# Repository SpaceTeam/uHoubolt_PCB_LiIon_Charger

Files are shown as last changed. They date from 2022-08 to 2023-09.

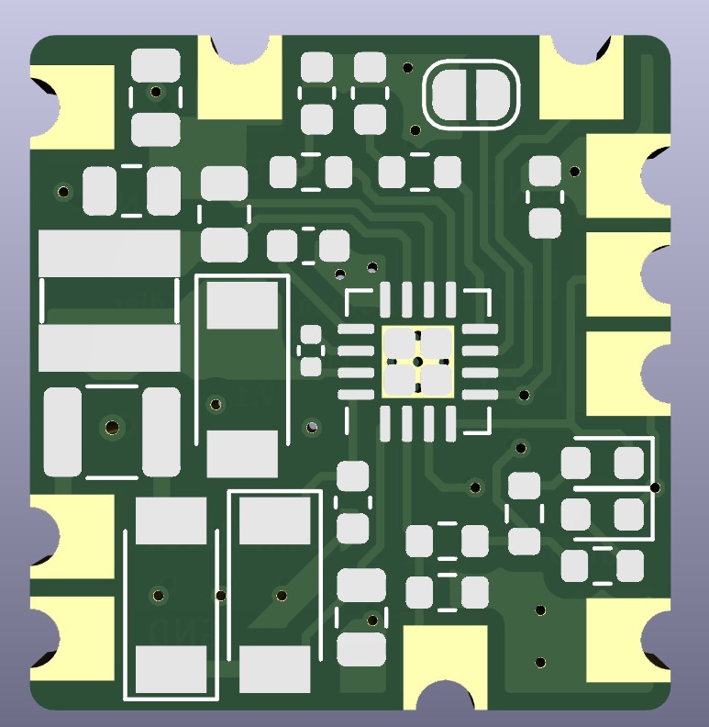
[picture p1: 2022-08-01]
LiIon_Charger_Front.jpg

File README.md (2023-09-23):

# uHoubolt LiIon Charger

Small sized PCB (19mm x 20mm). Used to control and monitor the charging process of a connected LiIon Battery. Soldered to the PMU via edge connectors. Most of the connectors serve a controling function to check the different circuits of the board.

## Features
- Edge connectors
- LED charging state indicator
- Footprint for the connecting PCB
- Known Issues
- The PCB is very noisy
- Did not properly work during EuRoC

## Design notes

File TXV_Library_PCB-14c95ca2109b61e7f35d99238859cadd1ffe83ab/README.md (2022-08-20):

# µHoubolt/Houbolt/TXV KiCad Library

## Usage
Add this repository to the KiCad project directory as a submodule

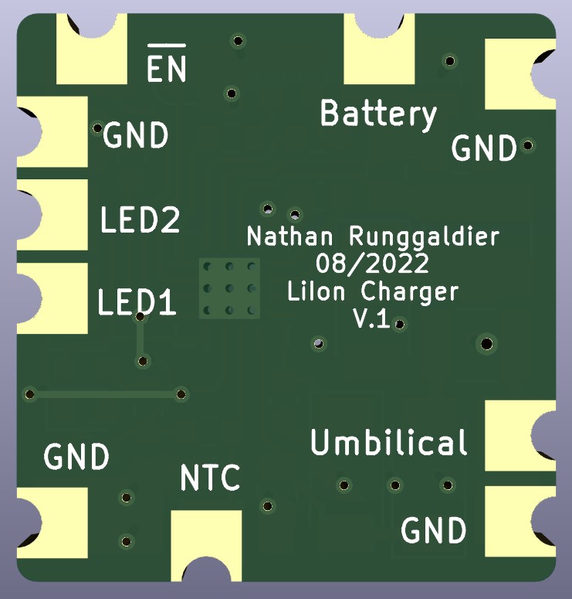
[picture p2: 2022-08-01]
LiIon_Charger_Back.jpg

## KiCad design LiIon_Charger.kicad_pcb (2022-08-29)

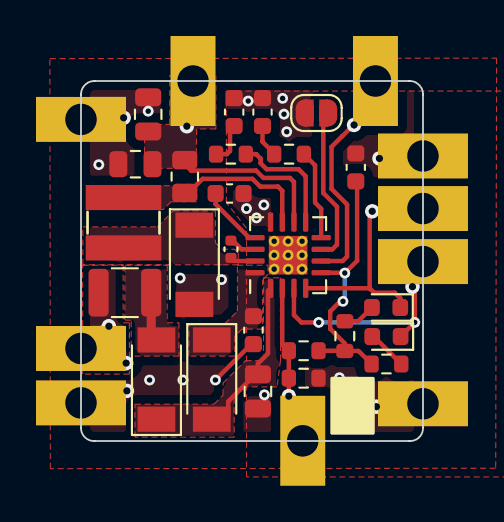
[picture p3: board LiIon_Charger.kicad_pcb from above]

Board: 2 copper layers, 19.0 x 20.0 mm, 35 parts (0 on the bottom side), 22 nets.

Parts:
C1, C8, C9: 22u; C_0805_2012Metric
C2, C3: 22u; C_0603_1608Metric
C4: 100n; C_0603_1608Metric
C5: 100n; C_0402_1005Metric
C6, C7: 2.2n; C_0603_1608Metric
D1, D4, D5: PMEG3050EP; D_SOD-128
D2, D3: LED; LED_0603_1608Metric
F1: Fuse_Small; R_1210_3225Metric
H1, H2, H3, H4: MountingHole_Pad; Edge_Connector
JP1: SolderJumper_2_Open; SolderJumper-2_P1.3mm_Open_RoundedPad1.0x1.5mm
L1: 4.7u; SRN4018TA-4R7M
R1, R2: 10k; R_0603_1608Metric
R3, R4: 120; R_0603_1608Metric
R5: 750; R_0603_1608Metric
R6: 2.61k; R_0603_1608Metric
R7: 200m; R_0805_2012Metric
U1: MP26123; QFN-16-1EP_4x4mm_P0.65mm_EP2.15x2.15mm_ThermalVias
j1, j2, j3, j4, j5, j6: Conn_01x01; Edge_Connector

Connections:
/Battery: C8.1, C9.1, R7.1, U1.10 (BATT), j6.1
/Charger: F1.1, j1.1
/NTC: R1.2, R2.1, U1.2 (NTC), j2.1
/~ACOK: D2.1 (K), U1.3 (~ACOK), j3.1
/~CHGOK: D3.1 (K), U1.4 (~CHGOK), j4.1
GND: C1.2, C2.2, C3.2, C4.2, C6.2, C7.2, C8.2, C9.2, D5.2 (A), H1.1, H2.1, H3.1, H4.1, JP1.2 (B), R2.2, U1.12 (GND)
unnamed: C1.1, D1.1 (K), D4.2 (A), U1.1 (VCC)
unnamed: C2.1, R1.1, R3.1, R4.1, U1.5 (VREF33)
unnamed: C3.1, D4.1 (K), U1.16 (VIN)
unnamed: C4.1, U1.13 (TMR)
unnamed: C5.1, D5.1 (K), L1.1, U1.15 (SW)
unnamed: C5.2, U1.14 (BST)
unnamed: C6.1, R6.1
unnamed: C7.1, R5.1
unnamed: D1.2 (A), F1.2
unnamed: D2.2 (A), R3.2
unnamed: D3.2 (A), R4.2
unnamed: JP1.1 (A), U1.7 (CELLS)
unnamed: L1.2, R7.2, U1.11 (CSP)
unnamed: R5.2, U1.9 (COMPI)
unnamed: R6.2, U1.8 (COMPV)
unnamed: U1.6 (~EN), j5.1

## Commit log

2022-08-20 Updated version
    Added planes and vias
    [LiIon_Charger.kicad_pcb, LiIon_Charger.kicad_sch]
2022-08-29 V1 Ordered
    [LiIon_Charger-B_Cu.gbl, LiIon_Charger-B_Mask.gbs, LiIon_Charger-B_Paste.gbp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]
